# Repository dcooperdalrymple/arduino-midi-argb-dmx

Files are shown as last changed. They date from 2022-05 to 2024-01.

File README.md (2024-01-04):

# Color Spray
> Convert Midi input to ARGB, RGBW, and DMX outputs with an Arduino.

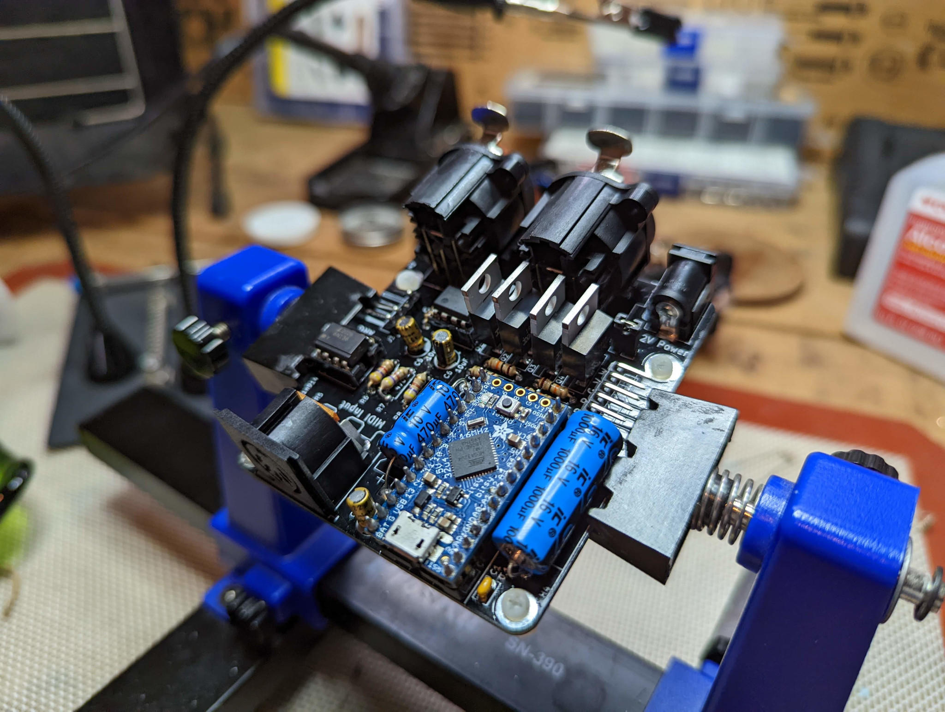
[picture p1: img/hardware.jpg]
Rev1 populated PCB


## Hardware
This project is designed specifically for the [Adafruit Itsy Bitsy 32u4 - 5V 16MHz](https://learn.adafruit.com/introducting-itsy-bitsy-32u4/), but any other Arduino-compatible MCU with similar specifications should be usable with minor modifications. The PCB design will require modification to use a different development board.

For 5V/12V RGBW operation, you can choose between NPN or N-channel MOSFETs in a TO-220 package _(ie: IRF540N, IRLB8721, or TIP-120)_. The resistors before the gate may not be necessary if you use a MOSFET, but are necessary if you use an NPN transistor. If you are using 5V LEDs, you'll need to bridge JP1 and make sure not to also plug a 12V source into the barrel jack at the same time or you may fry the arduino and any devices plugged into the ARGB connectors. If you use 12V LEDs, make sure that JP1 is not connected and provide a separate 12V power source into the barrel jack that is center-positive.

An XLR connector is provided as an alternative to the ARGB pin header. This connector is non-standard and is intended for custom installations where long, secure cable runs are desired. Avoid mixing the DMX and ARGB connections, though I've attempted to make their pinouts very similar to avoid shorting.

## Configuration
The device's configuration is stored within the internal EEPROM memory of the Atmel 32u4. If the appropriate configuration settings aren't already installed, the device will reformat the EEPROM to it's default settings. Midi SysEx messages are used in order to read and write new configuration settings.

A python-based configurator GUI program is provided to help read, backup, and write device configuration to the Color Spray. The program can be run after installing all [dependencies](configurator/manual.md#dependencies) by running `python configurator/configurator.py` from the root directory of the repository. More information is provided in the [manual](configurator/manual.md).

<p float="left">
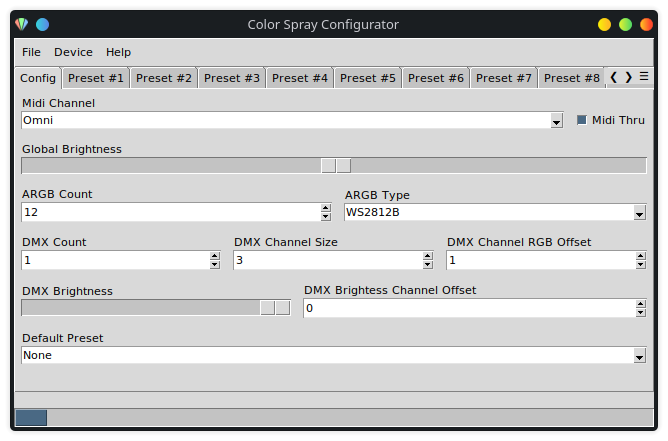
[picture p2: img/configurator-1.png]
Color Spray Configurator Config Panel
    
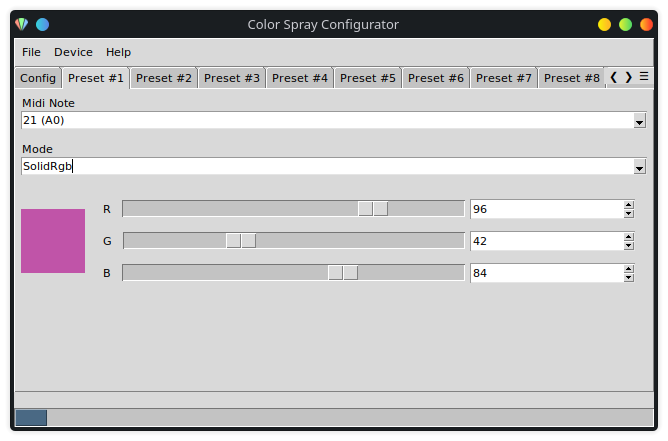
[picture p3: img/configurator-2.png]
Color Spray Configurator Preset Panel
    
</p>

## MIDI Implementation

### Configuration

> Depending on how the software is compiled and uploaded to the Arduino, you can use hardware UART Midi or USB Midi to control this device. The Rev1 PCB is configured with a DIN-5 Midi input only. Future revisions may include Midi output.

Change the `USB_MIDI` definition to enable USB Midi input support. The `MIDI_THRU` definition will enable Midi Thru support via hardware UART and USB if it is enabled.

By default, the `MIDI_CHANNEL` definition is set to Omni mode. This will accept all compatible incoming messages on any channel. Change the value of this definition to a number between 1-16 to assign this device to a particular Midi channel.

### Midi Thru

Some software-based Midi Thru functionality is included, but not all message types are supported. It is recommended that you use a hardware Midi Thru device in conjuction if you intend to use multiple devices on the same output.

### Program Change

> More program modes are planned for the future.

| Program | Description |
| --- | --- |
| 0 | Off |
| 1-15 | Load Preset # |
| 16 | Solid RGB |
| 17 | Solid HSV |
| 18 | Palette Cycle |
| 19 | Chase RGB |
| 20 | Chase HSV |

### Control Change

Control change messages are generally allocated to different General Purpose Controller functions and are separated for each program mode.

| Control | Function | Value (0-127, scaled) | Program |
| --- | --- | --- | --- |
| 12 | Palette | _See Available Palettes_ | Palette Cycle |
| 13 | Speed | 0-4 | Palette Cycle & Chase |
| 16 | Red | 0-254 | Solid RGB & Chase RGB |
| 17 | Green | 0-254 | Solid RGB & Chase RGB |
| 18 | Blue | 0-254 | Solid RGB & Chase RGB |
| 80 | Hue | 0-254 | Solid HSV & Chase HSV |
| 81 | Saturation | 0-254 | Solid HSV & Chase HSV |
| 82 | Value | 0-254 | Solid HSV & Chase HSV |
| 83 | Count | 1-8 | Chase RGB & Chase HSV |

#### Palettes

There are 8 palettes available all contributed by the _FastLED_ library. Custom palettes can be added relatively easily prior to compilation. See the [FastLED wiki](https://github.com/FastLED/FastLED/wiki/Gradient-color-palettes) for more details.

| Index | Midi CC Value | Palette |
| ----- | --- | --- |
| 0 | 0-15 | Cloud |
| 1 | 16-31 | Lava |
| 2 | 32-47 | Ocean |
| 3 | 48-63 | Forest |
| 4 | 64-79 | Rainbow |
| 5 | 80-95 | Rainbow Stripe |
| 6 | 96-111 | Party |
| 7 | 112-127 | Heat |

## DAW Plugins

> The only plugin provided for improved control and synchronization of this device is written for REAPER. The specifications are all provided for extending support to other platforms, but that is not planned currently.

### REAPER (JSFX)

Use the provided sliders to configure this device or enable trim automation on each setting to synchronize your lighting to your song.

Copy and paste `plugins/color-spray-jsfx` into your REAPER JSFX install directory (ie: .../REAPER/Effects). Add the plugin to a track in your project; it will be named _Color Spray_.

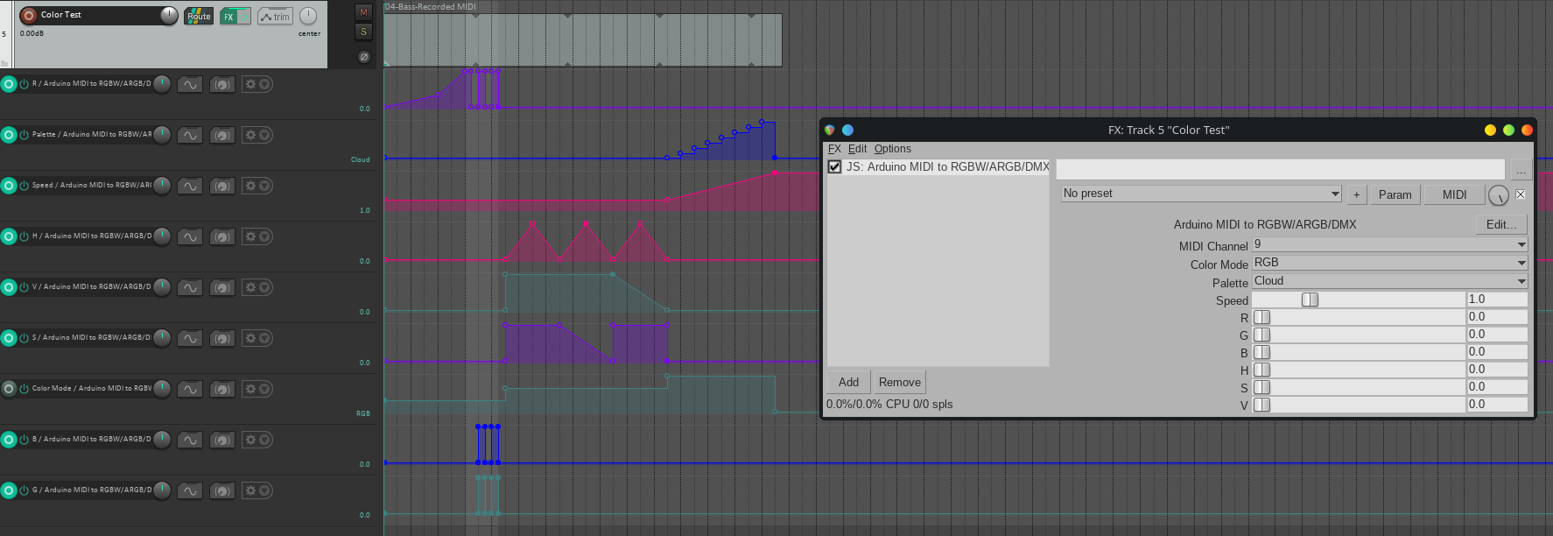
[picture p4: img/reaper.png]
REAPER plugin and example


## Software Dependencies
* [MIDI](https://github.com/FortySevenEffects/arduino_midi_library/)
* [Arduino USB-MIDI Transport](https://github.com/lathoub/Arduino-USBMIDI)
* [FastLED](https://fastled.io/)
* [DmxSimple](https://github.com/PaulStoffregen/DmxSimple)
* [digitalWriteFast](https://github.com/NicksonYap/digitalWriteFast)

---

[OSHW] US002117 | Certified open source hardware | oshwa.org/cert.

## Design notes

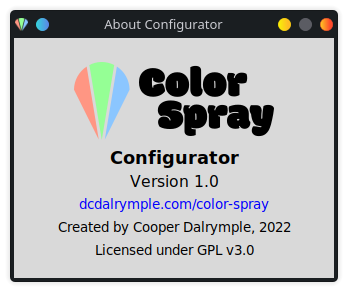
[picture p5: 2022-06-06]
img/configurator-3.png

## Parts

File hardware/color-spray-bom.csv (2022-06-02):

Source: | color-spray.kicad_sch
Date: | Mon 09 May 2022 02:39:10 PM CDT
Tool: | Eeschema 6.0.4+dfsg-1+b1
Generator: | /usr/share/kicad/plugins/bom_csv_grouped_by_value.py
Component Count: | 34
Individual Components:
Item | Qty | Reference(s) | Value | LibPart | Footprint | Datasheet
 |  | C1 | 0.1uF | Device:C | Capacitor_THT:C_Rect_L4.0mm_W2.5mm_P2.50mm | ~
 |  | C2 | 470uF | Device:C_Polarized | Capacitor_THT:CP_Axial_L20.0mm_D10.0mm_P26.00mm_Horizontal | ~
 |  | C3 | 10uF | Device:C_Polarized | Capacitor_THT:CP_Radial_D5.0mm_P2.50mm | ~
 |  | C4 | 1000uF | Device:C_Polarized | Capacitor_THT:CP_Axial_L20.0mm_D10.0mm_P26.00mm_Horizontal | ~
 |  | C5 | 10uF | Device:C_Polarized | Capacitor_THT:CP_Radial_D5.0mm_P2.50mm | ~
 |  | C6 | 10uF | Device:C_Polarized | Capacitor_THT:CP_Radial_D5.0mm_P2.50mm | ~
 |  | D1 | 1N914 | Diode:1N914 | Diode_THT:D_DO-35_SOD27_P7.62mm_Horizontal | http://www.vishay.com/docs/85622/1n914.pdf
 |  | H1 | Mount | Mechanical:MountingHole_Pad | MountingHole:MountingHole_3.2mm_M3_Pad | ~
 |  | H2 | Mount | Mechanical:MountingHole_Pad | MountingHole:MountingHole_3.2mm_M3_Pad | ~
 |  | H3 | Mount | Mechanical:MountingHole_Pad | MountingHole:MountingHole_3.2mm_M3_Pad | ~
 |  | H4 | Mount | Mechanical:MountingHole_Pad | MountingHole:MountingHole_3.2mm_M3_Pad | ~
 |  | J1 | MIDI Input | Connector:DIN-5_180degree | w_conn_av:din-5 | http://www.mouser.com/ds/2/18/40_c091_abd_e-75918.pdf
 |  | J2 | ARGB_XLR3 | Connector:XLR3_Ground | Connector_Audio:Jack_XLR_Neutrik_NC3FAAH2_Horizontal | ~
 |  | J3 | ARGB | Connector:Conn_01x04_Male | Connector_PinHeader_2.54mm:PinHeader_1x04_P2.54mm_Horizontal | ~
 |  | J4 | DMX_XLR3 | Connector:XLR3_Ground | Connector_Audio:Jack_XLR_Neutrik_NC3FAAH2_Horizontal | ~
 |  | J5 | External RGBW Power | Connector:Barrel_Jack | Connector_BarrelJack:BarrelJack_Horizontal | ~
 |  | J6 | RGBW | Connector:Conn_01x05_Male | Connector_PinHeader_2.54mm:PinHeader_1x05_P2.54mm_Horizontal | ~
 |  | JP1 | Jumper_2_Open | Jumper:Jumper_2_Open | Connector_PinHeader_2.54mm:PinHeader_1x02_P2.54mm_Vertical | ~
 |  | Q1 | IRLB8721PBF | Transistor_FET:IRLB8721PBF | Package_TO_SOT_THT:TO-220-3_Vertical | http://www.infineon.com/dgdl/irlb8721pbf.pdf?fileId=5546d462533600a40153566056732591
 |  | Q2 | IRLB8721PBF | Transistor_FET:IRLB8721PBF | Package_TO_SOT_THT:TO-220-3_Vertical | http://www.infineon.com/dgdl/irlb8721pbf.pdf?fileId=5546d462533600a40153566056732591
 |  | Q3 | IRLB8721PBF | Transistor_FET:IRLB8721PBF | Package_TO_SOT_THT:TO-220-3_Vertical | http://www.infineon.com/dgdl/irlb8721pbf.pdf?fileId=5546d462533600a40153566056732591
 |  | Q4 | IRLB8721PBF | Transistor_FET:IRLB8721PBF | Package_TO_SOT_THT:TO-220-3_Vertical | http://www.infineon.com/dgdl/irlb8721pbf.pdf?fileId=5546d462533600a40153566056732591
 |  | R1 | 1k | Device:R | Resistor_THT:R_Axial_DIN0207_L6.3mm_D2.5mm_P7.62mm_Horizontal | ~
 |  | R2 | 1k | Device:R | Resistor_THT:R_Axial_DIN0207_L6.3mm_D2.5mm_P7.62mm_Horizontal | ~
 |  | R3 | 1k | Device:R | Resistor_THT:R_Axial_DIN0207_L6.3mm_D2.5mm_P7.62mm_Horizontal | ~
 |  | R4 | 1k | Device:R | Resistor_THT:R_Axial_DIN0207_L6.3mm_D2.5mm_P7.62mm_Horizontal | ~
 |  | R5 | 220 | Device:R | Resistor_THT:R_Axial_DIN0207_L6.3mm_D2.5mm_P7.62mm_Horizontal | ~
 |  | R6 | 4.7k | Device:R | Resistor_THT:R_Axial_DIN0207_L6.3mm_D2.5mm_P7.62mm_Horizontal | ~
 |  | R7 | 470 | Device:R | Resistor_THT:R_Axial_DIN0207_L6.3mm_D2.5mm_P7.62mm_Horizontal | ~
 |  | R8 | 470 | Device:R | Resistor_THT:R_Axial_DIN0207_L6.3mm_D2.5mm_P7.62mm_Horizontal | ~
 |  | R9 | 100 | Device:R | Resistor_THT:R_Axial_DIN0207_L6.3mm_D2.5mm_P7.62mm_Horizontal | ~
 |  | U1 | ItsyBitsy-32u4-5V | ItsyBitsy 32u4 5V:ItsyBitsy-32u4-5V | itsybitsy-32u4-5v:ItsyBitsy_32u4
 |  | U2 | 6N138 | Isolator:6N138 | Package_DIP:DIP-8_W7.62mm_Socket_LongPads | http://www.onsemi.com/pub/Collateral/HCPL2731-D.pdf
 |  | U3 | SN75176AP | Interface_UART:SN75176AP | Package_DIP:DIP-8_W7.62mm_Socket_LongPads | http://www.ti.com/lit/ds/symlink/sn75176a.pdf
Collated Components:
Item | Qty | Reference(s) | Value | LibPart | Footprint | Datasheet
1 | 1 | C1 | 0.1uF | Device:C | Capacitor_THT:C_Rect_L4.0mm_W2.5mm_P2.50mm | ~
2 | 1 | C2 | 470uF | Device:C_Polarized | Capacitor_THT:CP_Axial_L20.0mm_D10.0mm_P26.00mm_Horizontal | ~
3 | 3 | C3, C5, C6 | 10uF | Device:C_Polarized | Capacitor_THT:CP_Radial_D5.0mm_P2.50mm | ~
4 | 1 | C4 | 1000uF | Device:C_Polarized | Capacitor_THT:CP_Axial_L20.0mm_D10.0mm_P26.00mm_Horizontal | ~
5 | 1 | D1 | 1N914 | Diode:1N914 | Diode_THT:D_DO-35_SOD27_P7.62mm_Horizontal | http://www.vishay.com/docs/85622/1n914.pdf
6 | 4 | H1, H2, H3, H4 | Mount | Mechanical:MountingHole_Pad | MountingHole:MountingHole_3.2mm_M3_Pad | ~
7 | 1 | J1 | MIDI Input | Connector:DIN-5_180degree | w_conn_av:din-5 | http://www.mouser.com/ds/2/18/40_c091_abd_e-75918.pdf
8 | 1 | J2 | ARGB_XLR3 | Connector:XLR3_Ground | Connector_Audio:Jack_XLR_Neutrik_NC3FAAH2_Horizontal | ~
9 | 1 | J3 | ARGB | Connector:Conn_01x04_Male | Connector_PinHeader_2.54mm:PinHeader_1x04_P2.54mm_Horizontal | ~
10 | 1 | J4 | DMX_XLR3 | Connector:XLR3_Ground | Connector_Audio:Jack_XLR_Neutrik_NC3FAAH2_Horizontal | ~
11 | 1 | J5 | External RGBW Power | Connector:Barrel_Jack | Connector_BarrelJack:BarrelJack_Horizontal | ~
12 | 1 | J6 | RGBW | Connector:Conn_01x05_Male | Connector_PinHeader_2.54mm:PinHeader_1x05_P2.54mm_Horizontal | ~
13 | 1 | JP1 | Jumper_2_Open | Jumper:Jumper_2_Open | Connector_PinHeader_2.54mm:PinHeader_1x02_P2.54mm_Vertical | ~
14 | 4 | Q1, Q2, Q3, Q4 | IRLB8721PBF | Transistor_FET:IRLB8721PBF | Package_TO_SOT_THT:TO-220-3_Vertical | http://www.infineon.com/dgdl/irlb8721pbf.pdf?fileId=5546d462533600a40153566056732591
15 | 4 | R1, R2, R3, R4 | 1k | Device:R | Resistor_THT:R_Axial_DIN0207_L6.3mm_D2.5mm_P7.62mm_Horizontal | ~
16 | 1 | R5 | 220 | Device:R | Resistor_THT:R_Axial_DIN0207_L6.3mm_D2.5mm_P7.62mm_Horizontal | ~
17 | 1 | R6 | 4.7k | Device:R | Resistor_THT:R_Axial_DIN0207_L6.3mm_D2.5mm_P7.62mm_Horizontal | ~
18 | 2 | R7, R8 | 470 | Device:R | Resistor_THT:R_Axial_DIN0207_L6.3mm_D2.5mm_P7.62mm_Horizontal | ~
19 | 1 | R9 | 100 | Device:R | Resistor_THT:R_Axial_DIN0207_L6.3mm_D2.5mm_P7.62mm_Horizontal | ~
20 | 1 | U1 | ItsyBitsy-32u4-5V | ItsyBitsy 32u4 5V:ItsyBitsy-32u4-5V | itsybitsy-32u4-5v:ItsyBitsy_32u4
21 | 1 | U2 | 6N138 | Isolator:6N138 | Package_DIP:DIP-8_W7.62mm_Socket_LongPads | http://www.onsemi.com/pub/Collateral/HCPL2731-D.pdf
22 | 1 | U3 | SN75176AP | Interface_UART:SN75176AP | Package_DIP:DIP-8_W7.62mm_Socket_LongPads | http://www.ti.com/lit/ds/symlink/sn75176a.pdf

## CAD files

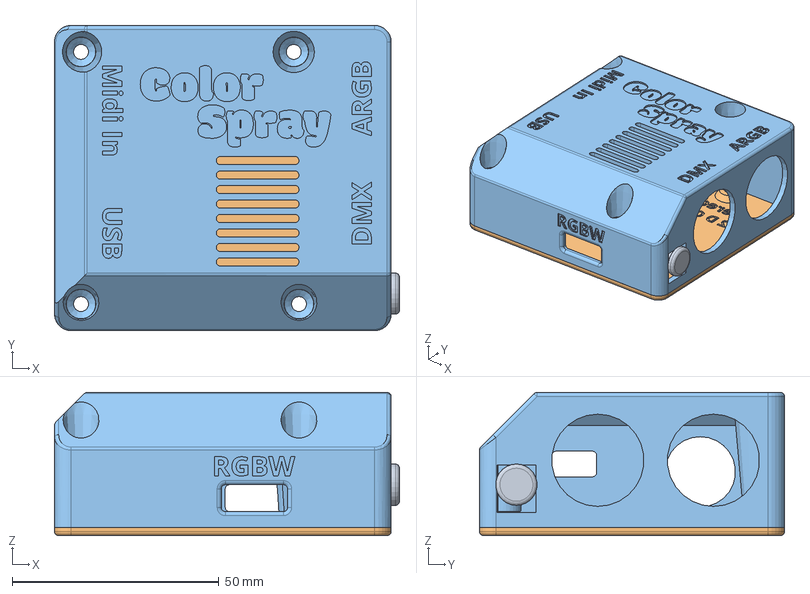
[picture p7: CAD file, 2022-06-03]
enclosure/color-spray.FCStd
83.4 x 73.8 x 34.6 mm
DC Cap
Lower Body with Labels
Upper Body with Labels

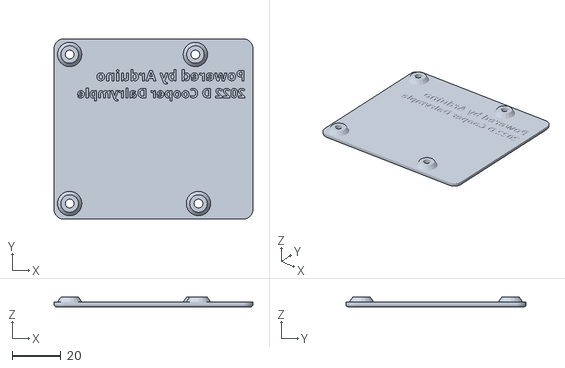
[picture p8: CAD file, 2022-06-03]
enclosure/bottom.stl
81.4 x 73.8 x 4.00

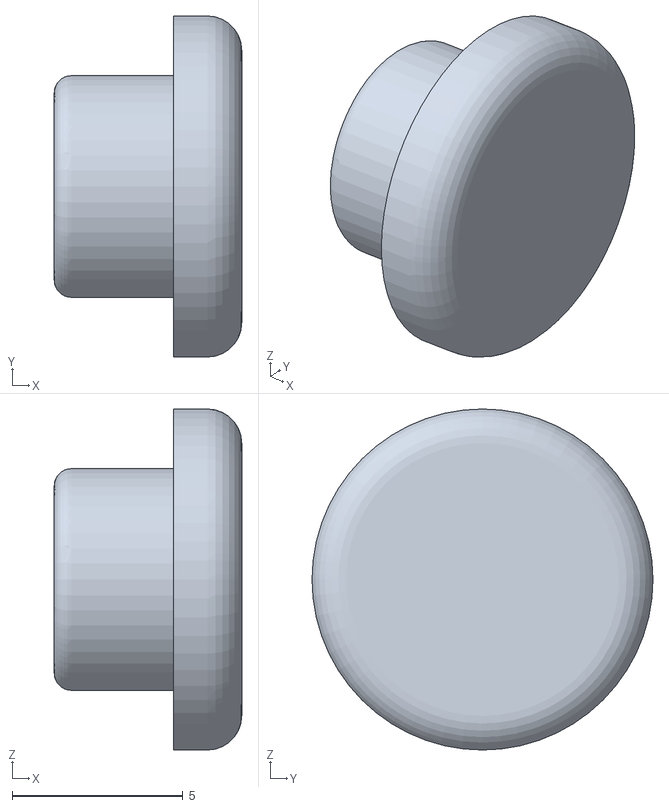
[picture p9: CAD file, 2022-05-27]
enclosure/dc-cap.stl
5.50 x 10.0 x 10.0

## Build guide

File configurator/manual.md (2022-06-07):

# Color Spray Configurator
> Configure the settings and presets of the Color Spray midi light controller.

## Table of Contents
1. [Config](#config)
   * [Midi Channel](#midi-channel)
   * [Midi Thru](#midi-thru)
   * [Global Brightness](#global-brightness)
   * [ARGB Count](#argb-count)
   * [ARGB Type](#argb-type)
   * [DMX](#dmx)
     * [Count](#dmx-count)
     * [Channel Size](#dmx-channel-size)
     * [RGB Offset](#dmx-rgb-offset)
     * [Brightness](#dmx-brightness)
     * [Brightness Channel](#dmx-brightness-channel)
2. [Presets](#preset)
   * [Program Number](#preset-program)
   * [Note](#preset-note)
   * [Mode](#preset-mode)
3. [Saving & Loading JSON Files](#json)
   * [Saving a JSON File](#json-save)
   * [Loading a JSON File](#json-load)
   * [Modifying JSON Files](#json-modify)
4. [Reading & Writing to Device](#device)
   * [Selecting the Device's Port](#device-port)
   * [Reading from the Device](#device-read)
   * [Writing from the Device](#device-write)
   * [Software Reset](#device-reset)
5. [Software Dependencies](#dependencies)

---

## Config<span id="config" />
The settings in this area will apply to all device operations. Most settings will take effect with a software reset after the device is written to, but some (such as the _ARGB Type_) may require a hardware reset before they take affect.

### Midi Channel<span id="midi-channel" />
Choose the desired midi channel to accept all midi messages: control change, program change, and note on. By default, the device is configured for _Omni_ mode where it will accept all messages. Changing the midi channel won't have any affect on reading and writing device configuration settings.

### Midi Thru<span id="midi-thru" />
If you'd like to transfer messages from the midi input to the output buffer, check the Midi Thru box. Messages will be transferred no matter what channel they are set to. The messages will be transferred according to the following table:

| Input Port | Output Ports |
| --- | --- |
| UART In | UART Out, USB Out |
| USB In | UART Out |

> To prevent unnecessary loopback, USB is not set in Thru mode.
> By leaving Midi Thru enabled, it may slow down the device's responsiveness. If not needed, it is recommended that you leave Midi Thru disabled.

### Global Brightness<span id="global-brightness" />
By default, this setting is set to 50% where the color settings are unaffected. Drag the brightness slider down to lower the overall color intensity or higher to increase and potentially wash out your colors.

### ARGB Count<span id="argb-count" />
To individually control each LED in an ARGB strip, you will need to predefine the number of LEDs with this setting. You are allowed a maximum of 128 addressable LEDs and a minimum of 1.

### ARGB Type<span id="argb-type" />
WD2812B is set as the default ARGB controller, but depending on the type of LEDs you are controlling, you may need to change this setting. You can find more information on each chipset type [here](https://github.com/FastLED/FastLED/wiki/Overview#supported-chipsets). More chipset than the provided are supported but will require firmware re-compilation to enable.

### DMX<span id="dmx" />
You can control DMX lights simultaneously all on the same channels, but if you'd like to address each DMX light independently, you can use the following settings.

> It is not currently possible to configure lights independently. It is recommended that you use the same types of RGB lights together to avoid channel overlaps. Independent DMX device configuration may come in a future release.

DMX communication is limited to 512 channels. Make sure that your settings don't exceed 512 channels in total. The calculation to determine the total number of channels is as follows: `Count * Channel Size`.

#### Count<span id="dmx-count" />
Specify the number of devices that you'd like to control. You must at least have 1 device accounted for.

#### Channel Size<span id="dmx-channel-size" />
Specify the number of channels each device will be allocated. You may have to look up the specifications for the device's DMX utilization. A minimum of 3 channels can be allotted to account for the RGB channels and a maximum of 32 channels per device is allowed.

#### RGB Offset<span id="dmx-rgb-offset" />
Your device may have its RGB channels start after the first channel. Pick a value between 1 and 2 less that the total channel size to correct control your specific lights.

> By default, the order of color channels is *RGB*. If you need to change this, the firmware will need to be recompiled with a different setting for the `DMX_ORDER` definition.

#### Brightness<span id="dmx-brightness" />
Your DMX lights may have a specific channel used to control the overal brightness of the lights. You can specify the static brightness amount using this slider. By default, the brightness is set at its max of 127.

#### Brightness Channel<span id="dmx-brightness-channel" />
If your device has a dedicated brightness channel, you can specify it here as an offset of each device's first channel. If you leave this setting as 0, the brightness channel will be ignored.

---

## Presets<span id="preset" />
The Color Spray has 15 presets available. Each preset contains the same settings which can be configured live with midi control commands. These presets can be loaded when the device boots up, when a midi program change message is received, or when a midi note on message is received if the device is configured to do so.

### Program Number<span id="preset-program" />
If a midi program change message is received, the Color Spray will load up the appropriate preset from 1-15. If the program # is 0, the device will be set to the `ColorOff` mode. Program #'s from 16+ are reserved for changing color modes dynamically.

The assigned index of the preset will be given by the name of the selected preset tab.

### Note<span id="preset-note" />
By assigning a note value to a preset, the preset can be loaded by sending a midi note on message to the device that matches the assigned pitch. If multiple presets are assigned to the same pitch, the preset whose program number comes first will be loaded.

### Mode<span id="preset-mode" />
By default, each preset is set to the color mode `ColorOff`. This essentially deactivates the preset and prevents any light from emitting from connected devices. The available modes and their functionality are listed below:

#### SolidRGB<span id="preset-mode-solidrgb" />
Set a solid RGB color for all lights to be set. The Red, Green, and Blue settings can be set between 0 and 127 and be controlled using the slider from left to right or by manually typing in your desired value in the number box. Use the preview window to help you find the desired color.

#### SolidHSV<span id="preset-mode-solidhsv" />
Set a solid HSV color for all lights to be set. The Hue, Saturation, and Value settings can be set between 0 and 127 and be controlled using the slider from left to right or by manually typing in your desired value in the number box. Use the preview window to help you find the desired color.

#### Palette<span id="preset-mode-palette" />
Loop through a pre-defined set of colors at a variable speed. There are 8 palette options available: Cloud, Lava, Ocean, Forest, Rainbow, Rainbow Stripe, Party, and Heat. A speed value is provided to define how fast the lights will rotate through the palette.

#### ChaseRGB<span id="preset-mode-chasergb" />
Rotate a solid RGB color around all available addressable lights in a "Chase" manner. You can control the desired _color_ using the SolidRGB settings, the _speed_ of the rotation, and the number of chase lights, _count_ (essentially the gap between the selected color).

#### ChaseHSV<span id="preset-mode-chasehsv" />
Rotate a solid HSV color around all available addressable lights in a "Chase" manner. You can control the desired _color_ using the SolidHSV settings, the _speed_ of the rotation, and the number of chase lights, _count_ (essentially the gap between the selected color).

---

## Saving & Loading JSON Files<span id="json" />
Before writing to the device, it is recommended that you save a backup copy of your settings to a safe location in your drive.

### Saving a JSON File<span id="json-save" />
Under the *File* menu in the top left, there is a *Save* and *Load* option. By clicking the *Save* option, it will open up a file prompt for you to select your desired file name and location. After clicking the OK button, a copy of all Config and Presets settings will be saved in the JSON format.

### Loading a JSON File<span id="json-load" />
If you have a previously saved configurator backup file available, you can load it using the *Load* option under the *File* menu in the top left corner of the window. A file prompt should appear where you can select the `*.json` file which you saved earlier. If an incompatible file is loaded, the program will prompt you that an error occurred and you will need to try again. Backup files saved with previous versions of the configurator software may not be compatible with the current software. When the file has finished loading, all of the controls within the configurator should be updated to show the new settings. If a device is connected, it will not be automatically synchronized in this process.

### Modifying JSON Files<span id="json-modify" />
If it fits your workflow style, you can modify the Color Spray JSON files outside of the configurator using any plain text editor. As long as the Manufacturer ID, Device ID, and Version settings remain unchanged, the configurator should attempt to load the altered file. It may be possible to affect the program in unforeseen ways, so only attempt this if you are willing to lose your original data and potentially harm the device's firmware.

---

## Reading & Writing to Device<span id="device" />
Communication with the _Color Spray_ occurs over a standard MIDI connection using the Sysex protocol. The device will need to be connected in duplex through either a hardware MIDI interface or with the built-in USB-MIDI interface of the device. A USB connection is highly recommended during this process for it's ease of use and reliability.

### Selecting the Device's Port<span id="device-port" />
A list of all MIDI devices available to your computer will be listed within the *Device* menu under *Ports*. If you haven't yet connected your device, you can do so then select the top item under *Ports* labeled *Refresh*. This will disconnect any midi connection you may have activated and refresh the list of available MIDI ports.

The USB-MIDI interface of the device should be labeled as `Color Spray 32u4`. Select this port in the menu to initialize the connection. If there is any issue, you should be prompted of the error.

### Reading from the Device<span id="device-read" />
Reading all device settings from the _Color Spray_ is very simple. Once you've connected to its MIDI port, you'll need to selected *Read* under the *Device* menu. This will check the status and firmware of the device to ensure compatibility then begin to load the global configuration settings and all 15 presets from the device's memory.

If the read completed successfully, all settings within the configurator program will be updated to reflect the settings of the device. If you'd like to make a backup of the devices settings for future use, now would be a great time.

If any errors occurred during the process, you should be notified of the exact error which occurred. You may need to attempt the process again or manually reset and reconnect to the device if you continue to have problems.

### Writing from the Device<span id="device-write" />
Once you are confident with all of your settings and presets and have made any necessary backups, you can write these settings to the device's memory by selecting *Write* under the *Device* menu.

This process will work very similarly to the read process but send the data in the opposite direction. If a device isn't found, your device's firmware is incompatible, or there are any other unforeseen errors in the process, the operation will cancel and you will be prompted of the error.

After the global configuration and all 15 presets have been written to the device's memory, a reset command will be automatically sent to the device for it to use the new settings and reinitialize any connected addressable lighting devices.

### Software Reset<span id="device-reset" />
For any reason if you'd like to manually reset the device's software, you can do so using the *Reset* option under the *Device* menu. This will not perform a hardware reset to the device but instead reload any stored settings and reinitialize the device's configuration.

If you'd like to perform a hardware reset which may be necessary to resolve some issues, you can do so either by powering off and powering on the device or by pressing the internal reset button which may require disassembly.

---

## Software Dependencies<span id="dependencies" />
In order to run the configurator too, you will need Python 3.0+ and a few pip packages. After you've resolved all dependencies, run the program using `python configurator.py`.

### Linux (Ubuntu/Debian)<span id="dependencies-linux" />
```
sudo apt-get update
sudo apt-get install python3 python3-pip python3-is-python
pip install tkinter python-rtmidi tkinterweb
```

### Windows<span id="dependencies-windows" />
Download and install the latest version of Python 3.0+ [here](https://www.python.org/downloads/windows/). PIP should be installed by default since Python 3.4. Within the command line, run the following command to install all dependencies: `python -m pip install tkinter python-rtmidi tkinterweb markdown`.

### Packages<span id="dependencies-packages" />
* [pyython-rtmidi](https://github.com/SpotlightKid/python-rtmidi)
* [tkinterweb](https://github.com/Andereoo/TkinterWeb/)
* [ttkScrollableNotebook](https://github.com/muhammeteminturgut/ttkScrollableNotebook) _(included within repository)_

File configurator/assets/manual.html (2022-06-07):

# Color Spray Configurator

Configure the settings and presets of the Color Spray midi light controller.

## Table of Contents

1. Config
  - Midi Channel
  - Midi Thru
  - Global Brightness
  - ARGB Count
  - ARGB Type
  - DMX
    - Count
    - Channel Size
    - RGB Offset
    - Brightness
    - Brightness Channel
2. Presets
  - Program Number
  - Note
  - Mode
3. Saving & Loading JSON Files
  - Saving a JSON File
  - Loading a JSON File
  - Modifying JSON Files
4. Reading & Writing to Device
  - Selecting the Device's Port
  - Reading from the Device
  - Writing from the Device
  - Software Reset
5. Software Dependencies

## Config

The settings in this area will apply to all device operations. Most settings will take effect with a software reset after the device is written to, but some (such as the ARGB Type) may require a hardware reset before they take affect.

### Midi Channel

Choose the desired midi channel to accept all midi messages: control change, program change, and note on. By default, the device is configured for Omni mode where it will accept all messages. Changing the midi channel won't have any affect on reading and writing device configuration settings.

### Midi Thru

If you'd like to transfer messages from the midi input to the output buffer, check the Midi Thru box. Messages will be transferred no matter what channel they are set to. The messages will be transferred according to the following table:

Input Port | Output Ports
UART In | UART Out, USB Out
USB In | UART Out

To prevent unnecessary loopback, USB is not set in Thru mode. By leaving Midi Thru enabled, it may slow down the device's responsiveness. If not needed, it is recommended that you leave Midi Thru disabled.

### Global Brightness

By default, this setting is set to 50% where the color settings are unaffected. Drag the brightness slider down to lower the overall color intensity or higher to increase and potentially wash out your colors.

### ARGB Count

To individually control each LED in an ARGB strip, you will need to predefine the number of LEDs with this setting. You are allowed a maximum of 128 addressable LEDs and a minimum of 1.

### ARGB Type

WD2812B is set as the default ARGB controller, but depending on the type of LEDs you are controlling, you may need to change this setting. You can find more information on each chipset type here (https://github.com/FastLED/FastLED/wiki/Overview#supported-chipsets). More chipset than the provided are supported but will require firmware re-compilation to enable.

### DMX

You can control DMX lights simultaneously all on the same channels, but if you'd like to address each DMX light independently, you can use the following settings.

It is not currently possible to configure lights independently. It is recommended that you use the same types of RGB lights together to avoid channel overlaps. Independent DMX device configuration may come in a future release.

DMX communication is limited to 512 channels. Make sure that your settings don't exceed 512 channels in total. The calculation to determine the total number of channels is as follows: Count * Channel Size.

#### Count

Specify the number of devices that you'd like to control. You must at least have 1 device accounted for.

#### Channel Size

Specify the number of channels each device will be allocated. You may have to look up the specifications for the device's DMX utilization. A minimum of 3 channels can be allotted to account for the RGB channels and a maximum of 32 channels per device is allowed.

#### RGB Offset

Your device may have its RGB channels start after the first channel. Pick a value between 1 and 2 less that the total channel size to correct control your specific lights.

By default, the order of color channels is RGB. If you need to change this, the firmware will need to be recompiled with a different setting for the DMX_ORDER definition.

#### Brightness

Your DMX lights may have a specific channel used to control the overal brightness of the lights. You can specify the static brightness amount using this slider. By default, the brightness is set at its max of 127.

#### Brightness Channel

If your device has a dedicated brightness channel, you can specify it here as an offset of each device's first channel. If you leave this setting as 0, the brightness channel will be ignored.

## Presets

The Color Spray has 15 presets available. Each preset contains the same settings which can be configured live with midi control commands. These presets can be loaded when the device boots up, when a midi program change message is received, or when a midi note on message is received if the device is configured to do so.

### Program Number

If a midi program change message is received, the Color Spray will load up the appropriate preset from 1-15. If the program # is 0, the device will be set to the ColorOff mode. Program #'s from 16+ are reserved for changing color modes dynamically.

The assigned index of the preset will be given by the name of the selected preset tab.

### Note

By assigning a note value to a preset, the preset can be loaded by sending a midi note on message to the device that matches the assigned pitch. If multiple presets are assigned to the same pitch, the preset whose program number comes first will be loaded.

### Mode

By default, each preset is set to the color mode ColorOff. This essentially deactivates the preset and prevents any light from emitting from connected devices. The available modes and their functionality are listed below:

#### SolidRGB

Set a solid RGB color for all lights to be set. The Red, Green, and Blue settings can be set between 0 and 127 and be controlled using the slider from left to right or by manually typing in your desired value in the number box. Use the preview window to help you find the desired color.

#### SolidHSV

Set a solid HSV color for all lights to be set. The Hue, Saturation, and Value settings can be set between 0 and 127 and be controlled using the slider from left to right or by manually typing in your desired value in the number box. Use the preview window to help you find the desired color.

#### Palette

Loop through a pre-defined set of colors at a variable speed. There are 8 palette options available: Cloud, Lava, Ocean, Forest, Rainbow, Rainbow Stripe, Party, and Heat. A speed value is provided to define how fast the lights will rotate through the palette.

#### ChaseRGB

Rotate a solid RGB color around all available addressable lights in a "Chase" manner. You can control the desired color using the SolidRGB settings, the speed of the rotation, and the number of chase lights, count (essentially the gap between the selected color).

#### ChaseHSV

Rotate a solid HSV color around all available addressable lights in a "Chase" manner. You can control the desired color using the SolidHSV settings, the speed of the rotation, and the number of chase lights, count (essentially the gap between the selected color).

## Saving & Loading JSON Files

Before writing to the device, it is recommended that you save a backup copy of your settings to a safe location in your drive.

### Saving a JSON File

Under the File menu in the top left, there is a Save and Load option. By clicking the Save option, it will open up a file prompt for you to select your desired file name and location. After clicking the OK button, a copy of all Config and Presets settings will be saved in the JSON format.

### Loading a JSON File

If you have a previously saved configurator backup file available, you can load it using the Load option under the File menu in the top left corner of the window. A file prompt should appear where you can select the *.json file which you saved earlier. If an incompatible file is loaded, the program will prompt you that an error occurred and you will need to try again. Backup files saved with previous versions of the configurator software may not be compatible with the current software. When the file has finished loading, all of the controls within the configurator should be updated to show the new settings. If a device is connected, it will not be automatically synchronized in this process.

### Modifying JSON Files

If it fits your workflow style, you can modify the Color Spray JSON files outside of the configurator using any plain text editor. As long as the Manufacturer ID, Device ID, and Version settings remain unchanged, the configurator should attempt to load the altered file. It may be possible to affect the program in unforeseen ways, so only attempt this if you are willing to lose your original data and potentially harm the device's firmware.

## Reading & Writing to Device

Communication with the Color Spray occurs over a standard MIDI connection using the Sysex protocol. The device will need to be connected in duplex through either a hardware MIDI interface or with the built-in USB-MIDI interface of the device. A USB connection is highly recommended during this process for it's ease of use and reliability.

### Selecting the Device's Port

A list of all MIDI devices available to your computer will be listed within the Device menu under Ports. If you haven't yet connected your device, you can do so then select the top item under Ports labeled Refresh. This will disconnect any midi connection you may have activated and refresh the list of available MIDI ports.

The USB-MIDI interface of the device should be labeled as Color Spray 32u4. Select this port in the menu to initialize the connection. If there is any issue, you should be prompted of the error.

### Reading from the Device

Reading all device settings from the Color Spray is very simple. Once you've connected to its MIDI port, you'll need to selected Read under the Device menu. This will check the status and firmware of the device to ensure compatibility then begin to load the global configuration settings and all 15 presets from the device's memory.

If the read completed successfully, all settings within the configurator program will be updated to reflect the settings of the device. If you'd like to make a backup of the devices settings for future use, now would be a great time.

If any errors occurred during the process, you should be notified of the exact error which occurred. You may need to attempt the process again or manually reset and reconnect to the device if you continue to have problems.

### Writing from the Device

Once you are confident with all of your settings and presets and have made any necessary backups, you can write these settings to the device's memory by selecting Write under the Device menu.

This process will work very similarly to the read process but send the data in the opposite direction. If a device isn't found, your device's firmware is incompatible, or there are any other unforeseen errors in the process, the operation will cancel and you will be prompted of the error.

After the global configuration and all 15 presets have been written to the device's memory, a reset command will be automatically sent to the device for it to use the new settings and reinitialize any connected addressable lighting devices.

### Software Reset

For any reason if you'd like to manually reset the device's software, you can do so using the Reset option under the Device menu. This will not perform a hardware reset to the device but instead reload any stored settings and reinitialize the device's configuration.

If you'd like to perform a hardware reset which may be necessary to resolve some issues, you can do so either by powering off and powering on the device or by pressing the internal reset button which may require disassembly.

## Software Dependencies

In order to run the configurator too, you will need Python 3.0+ and a few pip packages. After you've resolved all dependencies, run the program using python configurator.py.

### Linux (Ubuntu/Debian)

sudo apt-get update
sudo apt-get install python3 python3-pip python3-is-python
pip install tkinter python-rtmidi tkinterweb

### Windows

Download and install the latest version of Python 3.0+ here (https://www.python.org/downloads/windows/). PIP should be installed by default since Python 3.4. Within the command line, run the following command to install all dependencies: python -m pip install tkinter python-rtmidi tkinterweb.

### Packages

- pyython-rtmidi (https://github.com/SpotlightKid/python-rtmidi)
- tkinterweb (https://github.com/Andereoo/TkinterWeb/)
- ttkScrollableNotebook (https://github.com/muhammeteminturgut/ttkScrollableNotebook) (included within repository)

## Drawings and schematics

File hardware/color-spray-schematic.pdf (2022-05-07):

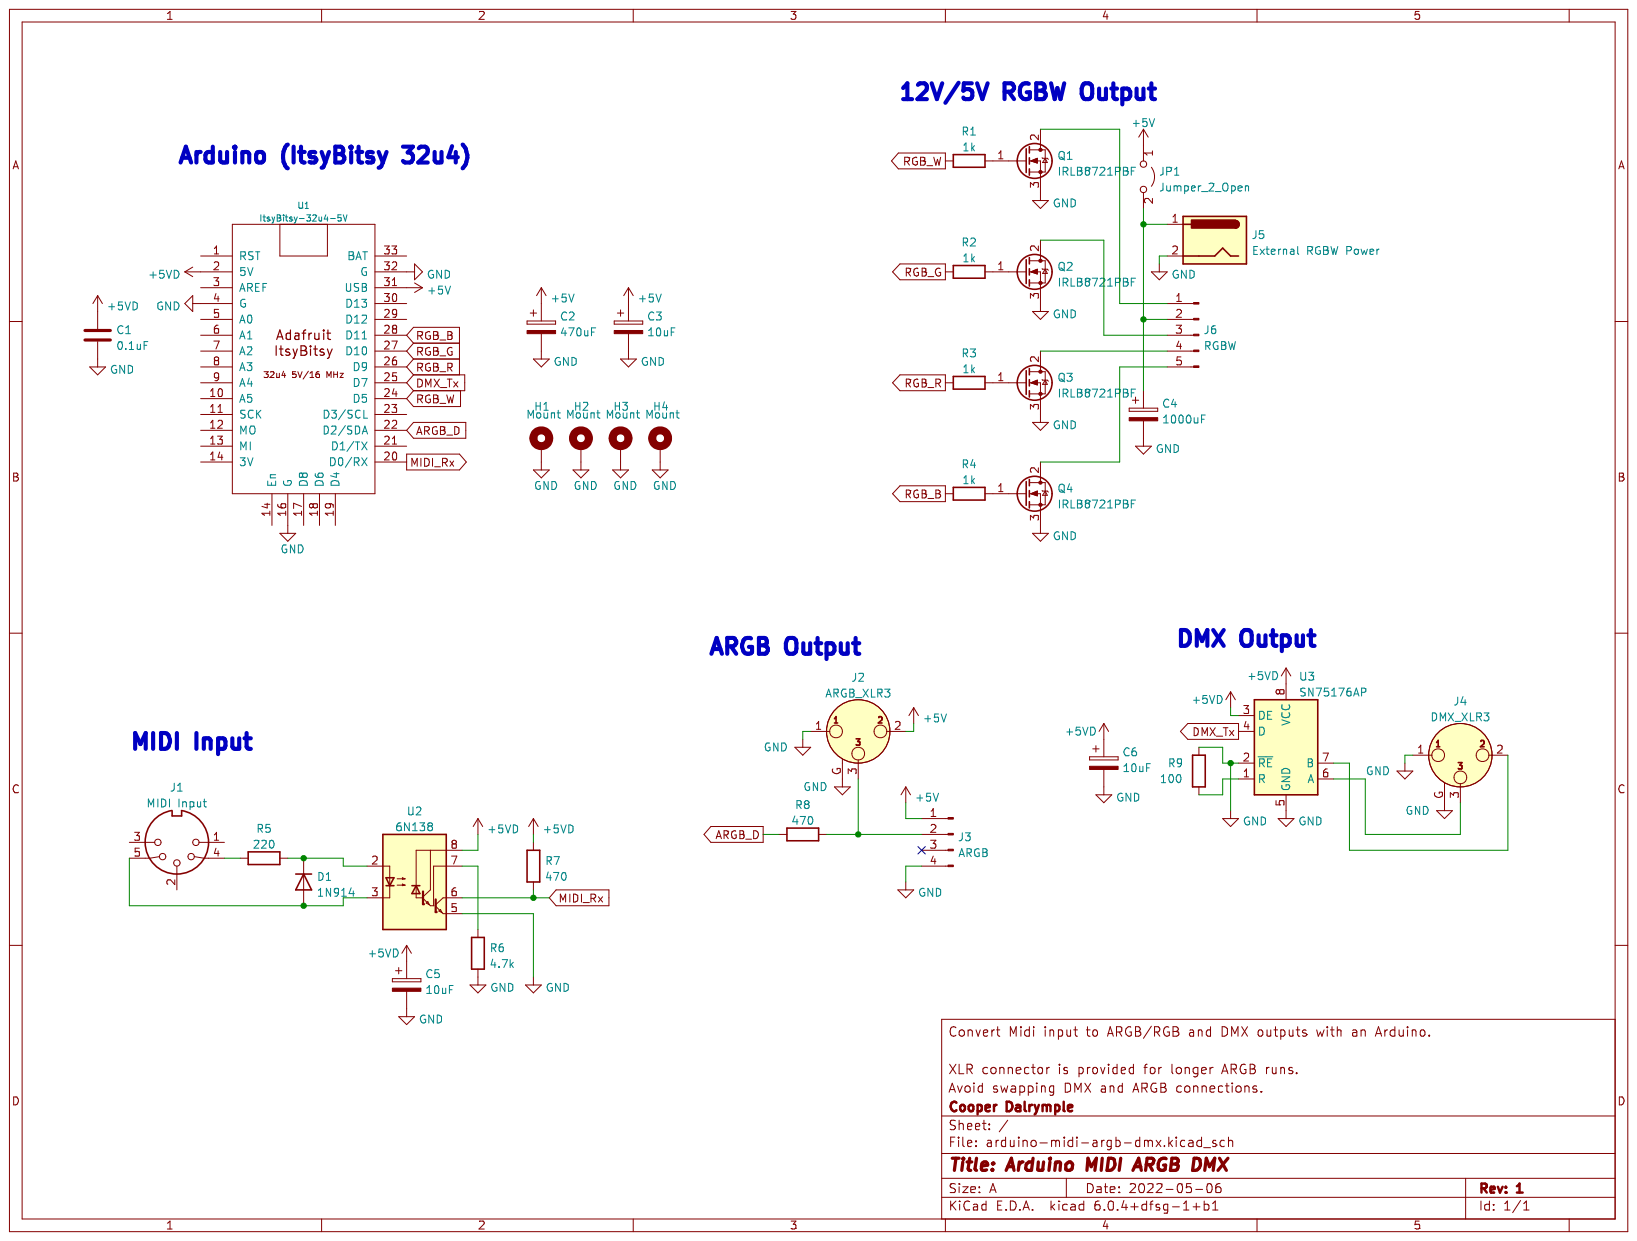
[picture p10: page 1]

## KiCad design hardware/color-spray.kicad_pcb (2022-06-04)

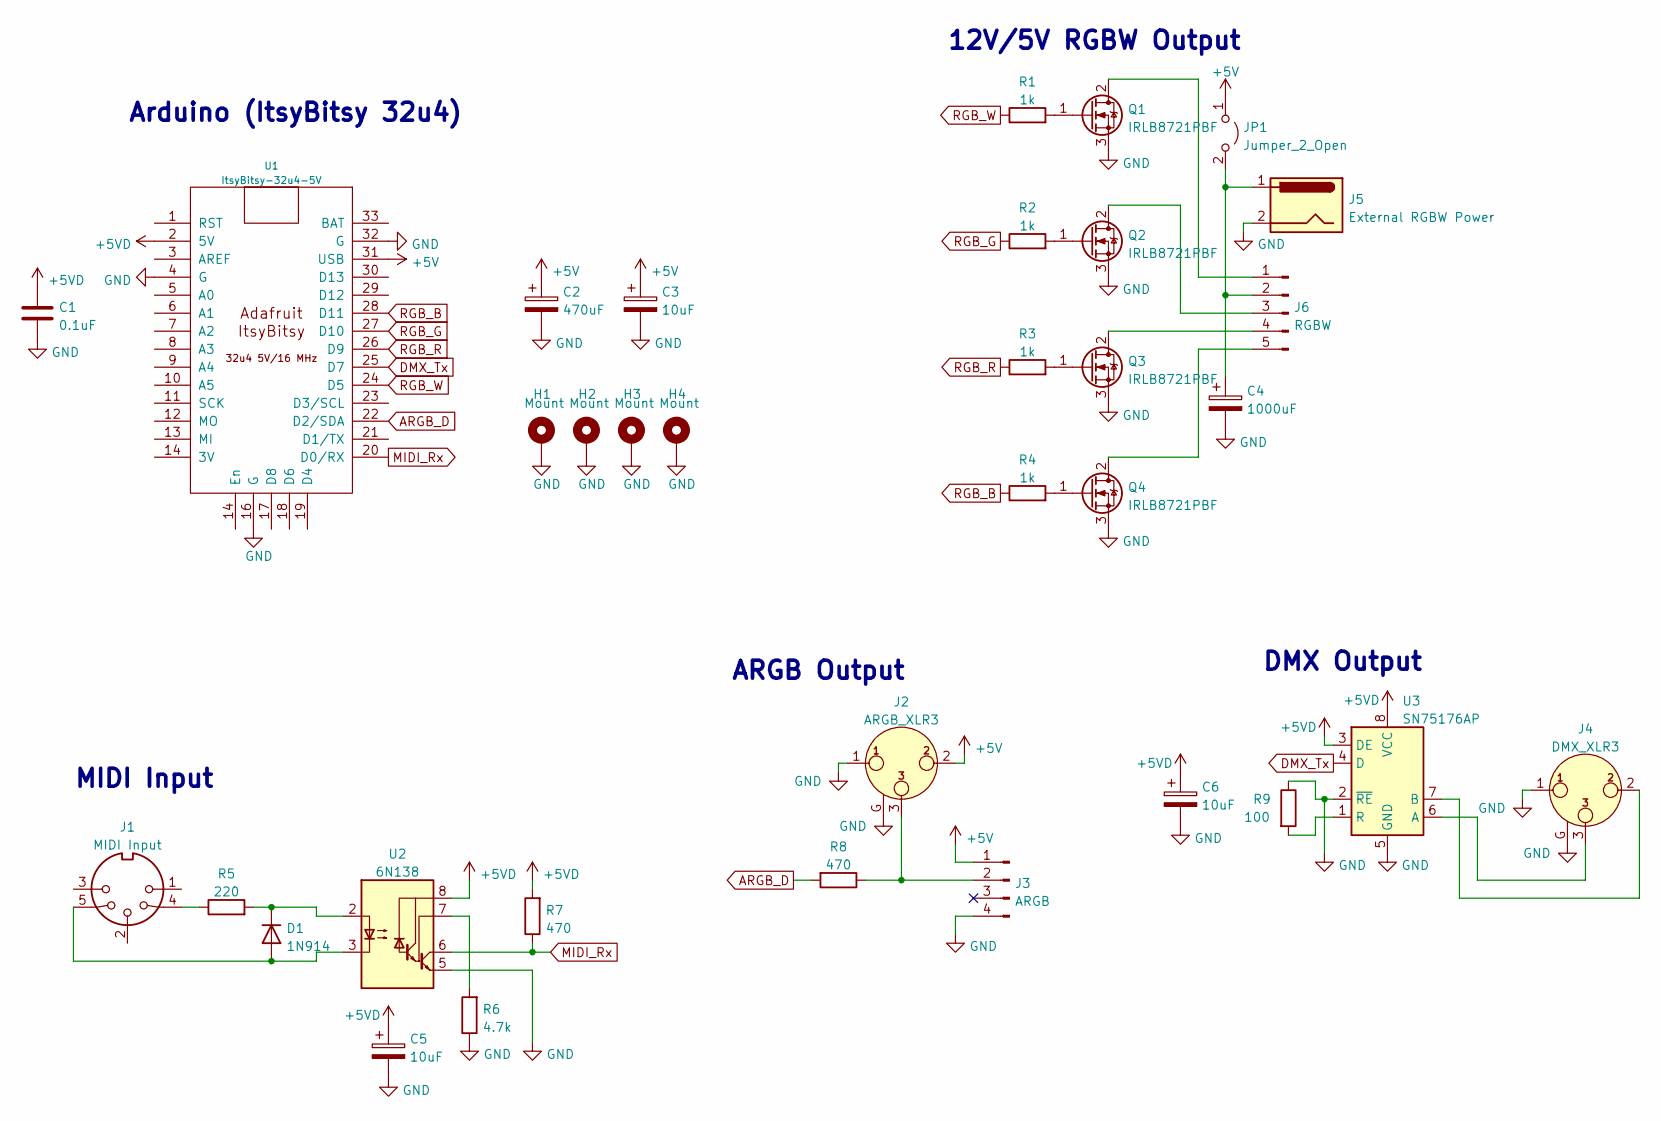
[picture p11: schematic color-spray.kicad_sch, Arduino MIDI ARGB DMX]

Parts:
C1: 0.1uF; C_Rect_L4.0mm_W2.5mm_P2.50mm
C2: 470uF; CP_Axial_L20.0mm_D10.0mm_P26.00mm_Horizontal
C3, C5, C6: 10uF; CP_Radial_D5.0mm_P2.50mm
C4: 1000uF; CP_Axial_L20.0mm_D10.0mm_P26.00mm_Horizontal
D1: 1N914; D_DO-35_SOD27_P7.62mm_Horizontal
H1, H2, H3, H4: Mount; MountingHole_3.2mm_M3_Pad
J1: MIDI Input; din-5
J2: ARGB_XLR3; Jack_XLR_Neutrik_NC3FAAH2_Horizontal
J3: ARGB; PinHeader_1x04_P2.54mm_Horizontal
J4: DMX_XLR3; Jack_XLR_Neutrik_NC3FAAH2_Horizontal
J5: External RGBW Power; BarrelJack_Horizontal
J6: RGBW; PinHeader_1x05_P2.54mm_Horizontal
JP1: Jumper_2_Open; PinHeader_1x02_P2.54mm_Vertical
Q1, Q2, Q3, Q4: IRLB8721PBF; TO-220-3_Vertical
R1, R2, R3, R4: 1k; R_Axial_DIN0207_L6.3mm_D2.5mm_P7.62mm_Horizontal
R5: 220; R_Axial_DIN0207_L6.3mm_D2.5mm_P7.62mm_Horizontal
R6: 4.7k; R_Axial_DIN0207_L6.3mm_D2.5mm_P7.62mm_Horizontal
R7, R8: 470; R_Axial_DIN0207_L6.3mm_D2.5mm_P7.62mm_Horizontal
R9: 100; R_Axial_DIN0207_L6.3mm_D2.5mm_P7.62mm_Horizontal
U1: ItsyBitsy-32u4-5V; ItsyBitsy_32u4
U2: 6N138; DIP-8_W7.62mm_Socket_LongPads
U3: SN75176AP; DIP-8_W7.62mm_Socket_LongPads

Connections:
+5V: C2.1, C3.1, J2.2, J3.1, JP1.1 (A), U1.31 (USB)
+5VD: C1.1, C5.1, C6.1, R7.2, U1.2 (5V), U2.8 (VCC), U3.3 (DE), U3.8 (VCC)
ARGB_D: R8.2, U1.22 (D2/SDA)
DMX_Tx: U1.25 (D7), U3.4 (D)
GND: C1.2, C2.2, C3.2, C4.2, C5.2, C6.2, H1.1, H2.1, H3.1, H4.1, J2.1, J2.G, J3.4, J4.1, J4.G, J5.2, Q1.3 (S), Q2.3 (S), Q3.3 (S), Q4.3 (S), R6.1, R9.1, U1.4 (G), U1.16 (G), U1.32 (G), U2.5 (GND), U3.2 (~RE), U3.5 (GND)
MIDI_Rx: R7.1, U1.20 (D0/RX), U2.6 (VO2)
unnamed: C4.1, J5.1, J6.2, JP1.2 (B)
unnamed: J1.4, R5.1
unnamed: D1.2 (A), J1.5, U2.3 (C2)
unnamed: J2.3, J3.2, R8.1
unnamed: J4.2, U3.7 (B)
unnamed: J4.3, U3.6 (A)
unnamed: J6.3, Q2.2 (D)
unnamed: J6.4, Q3.2 (D)
unnamed: J6.5, Q4.2 (D)
unnamed: J6.1, Q1.2 (D)
unnamed: Q1.1 (G), R1.2
unnamed: Q2.1 (G), R2.2
unnamed: Q3.1 (G), R3.2
unnamed: Q4.1 (G), R4.2
unnamed: D1.1 (K), R5.2, U2.2 (C1)
unnamed: R6.2, U2.7 (VO1)
unnamed: R9.2, U3.1 (R)
RGB_B: R4.1, U1.28 (D11)
RGB_G: R2.1, U1.27 (D10)
RGB_R: R3.1, U1.26 (D9)
RGB_W: R1.1, U1.24 (D5)

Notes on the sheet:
MIDI Input
Arduino (ItsyBitsy 32u4)
ARGB Output
12V/5V RGBW Output
DMX Output

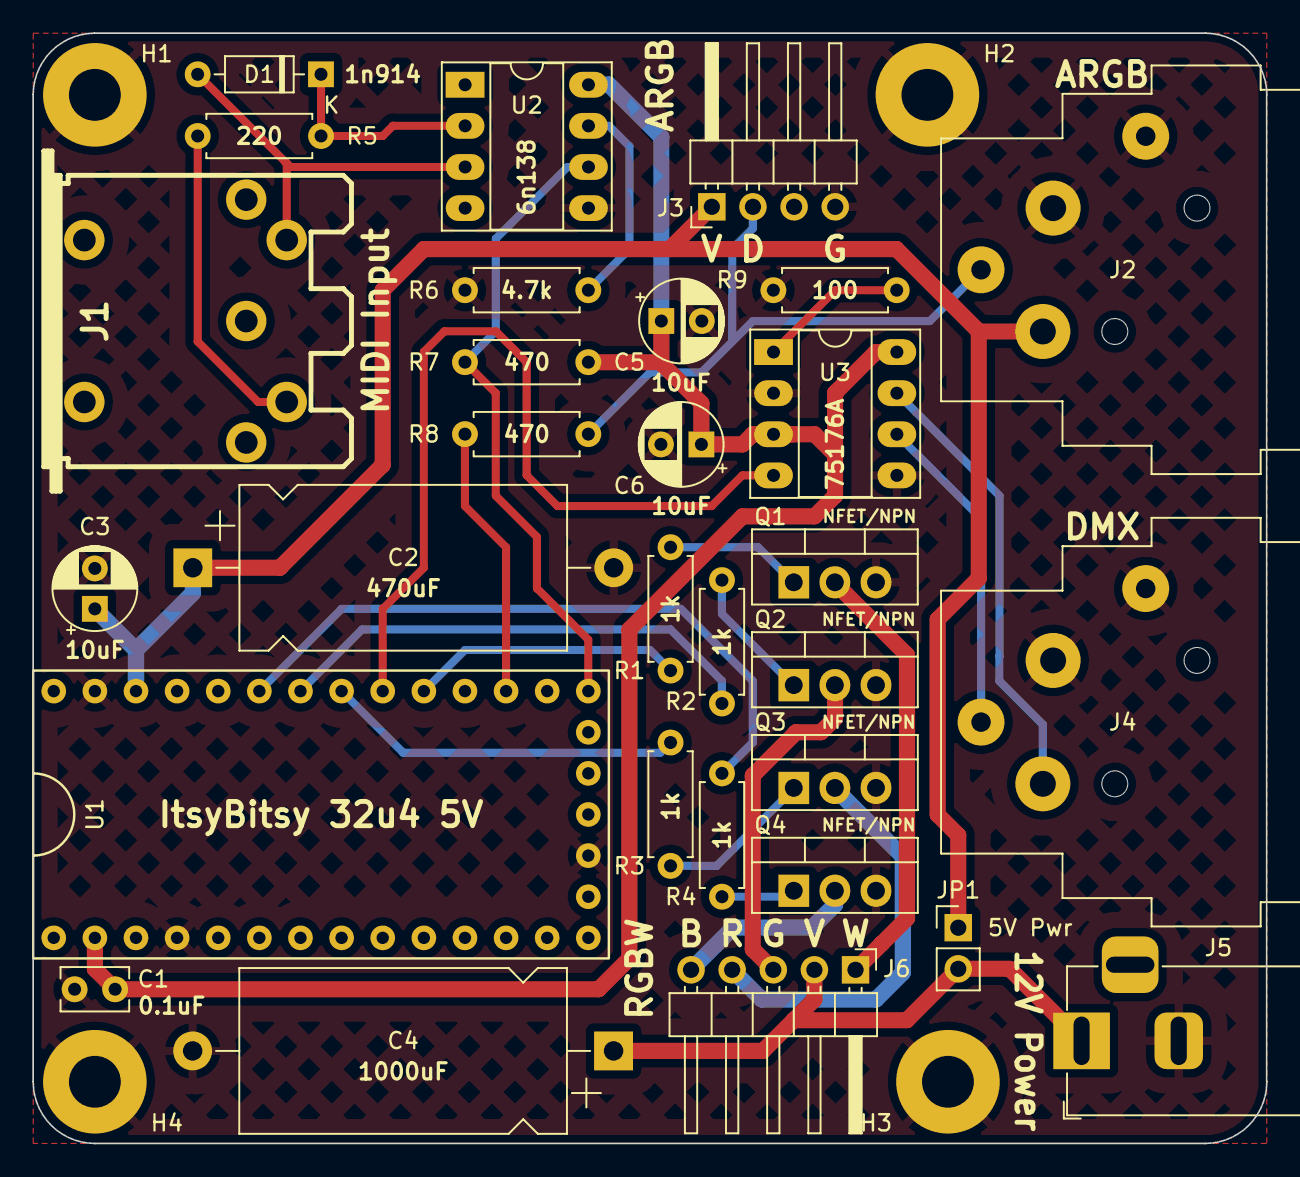
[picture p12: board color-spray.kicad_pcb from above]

Board: 2 copper layers, 76.2 x 68.6 mm, 34 parts (0 on the bottom side), 27 nets.

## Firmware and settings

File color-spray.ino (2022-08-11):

/**
 * Title:       Color Spray
 * Created by:  Cooper Dalrymple
 * Date:        2022-05-06
 * License:     GNU GPL v3.0
 * Version:     1.0
 */

#define ARGB_ENABLED    true
#define DMX_ENABLED     true
#define RGBW_ENABLED    true

#define USB_MIDI        true
#define USB_TIMEOUT     2000 // Only used for serial debugging

#if USB_MIDI
#include <USB-MIDI.h>
#else
#include <MIDI.h>
#endif
USING_NAMESPACE_MIDI;

struct CustomMidiSettings : public MIDI_NAMESPACE::DefaultSettings {
    static const unsigned SysExMaxSize = 32;
};
typedef Message<CustomMidiSettings::SysExMaxSize> MidiMessage;
typedef MIDI_NAMESPACE::MidiType MidiType;

#if USB_MIDI
#define UsbMidiMessage MIDI_NAMESPACE::MidiInterface<USBMIDI_NAMESPACE::usbMidiTransport, CustomMidiSettings>::MidiMessage
USBMIDI_CREATE_CUSTOM_INSTANCE(0, MIDICoreUSB, CustomMidiSettings);
#endif

#define SerialMidiMessage MIDI_NAMESPACE::MidiInterface<MIDI_NAMESPACE::SerialMIDI<HardwareSerial>, CustomMidiSettings>::MidiMessage
MIDI_CREATE_CUSTOM_INSTANCE(HardwareSerial, Serial1, MIDICoreSerial, CustomMidiSettings);

#if ARGB_ENABLED
#include "controller_argb.h"
#endif
#if DMX_ENABLED
#include "controller_dmx.h"
#endif
#if RGBW_ENABLED
#include "controller_rgbw.h"
#endif

#include "sysex.h"
#include "color.h"
#include "palettes.h"
#include "preset.h"
#include "settings.h"

#define LED             13
#define LED_DURATION    10

#define ARGB_MAX        120
#if ARGB_ENABLED
#define ARGB_PIN        2
#define ARGB_ORDER      GRB
#define ARGB_TYPE       WS2812B
static ARGB_TYPE<ARGB_PIN, ARGB_ORDER> argbController;
uint8_t modArgb = 1;
#endif

#define DMX_MAX         32
#if DMX_ENABLED
#define DMX_PIN         7
#define DMX_ORDER       RGB
static DmxController<DMX_PIN, DMX_ORDER> dmxController;
uint8_t modDmx = 1;
#endif

#if RGBW_ENABLED
#define RGBW_R           9
#define RGBW_G           10
#define RGBW_B           11
#define RGBW_W           5
static RgbwController<RGBW_R, RGBW_G, RGBW_B, RGBW_W> rgbwController;
#endif

#define COLOR_UPDATE    10 // ms
#define PALETTE_UPDATE  2 // ms
#define PALETTE_CHANGES 48
#define PALETTE_ITERS   1
#define PALETTE_MAX     16
#define PALETTE_BLEND   LINEARBLEND
PresetData current_preset = default_preset;
CRGBPalette16 current_palette(CRGB::Black);

Settings settings;

void configure();
void loadPreset(uint8_t i);

#if USB_MIDI
void messageUartToUsb(MidiMessage message);
void messageUsbToUart(MidiMessage message);
#endif
void controlChange(byte channel, byte control, byte value);
void programChange(byte channel, byte program);

void setup() {
    pinMode(LED, OUTPUT);
    digitalWrite(LED, HIGH);

    pinMode(0, INPUT);
    pinMode(1, OUTPUT);

    #if USB_MIDI
    #else
    Serial.begin(9600);
    #endif

    #if USB_MIDI
    MIDICoreSerial.setHandleMessage(messageUartToUsb);
    #endif
    MIDICoreSerial.setHandleControlChange(controlChange);
    MIDICoreSerial.setHandleProgramChange(programChange);
    MIDICoreSerial.setHandleNoteOn(noteOn);
    MIDICoreSerial.setHandleSystemExclusive(systemExclusive);

    #if USB_MIDI
    MIDICoreUSB.turnThruOff();
    MIDICoreUSB.setHandleMessage(messageUsbToUart);
    MIDICoreUSB.setHandleControlChange(controlChange);
    MIDICoreUSB.setHandleProgramChange(programChange);
    MIDICoreUSB.setHandleNoteOn(noteOn);
    MIDICoreUSB.setHandleSystemExclusive(systemExclusive);
    #endif

    MIDICoreSerial.begin(MIDI_CHANNEL_OMNI);
    #if USB_MIDI
    MIDICoreUSB.begin(MIDI_CHANNEL_OMNI);
    #endif

    configure();

    digitalWrite(LED, LOW); // Indicate that initialization is complete
}

void configure() {
    #if USB_MIDI
    #else
    unsigned long usb_start = millis();
    while (!Serial && millis() - usb_start < USB_TIMEOUT) { }
    if (Serial) {
        Serial.println(F("Color Spray - Version 1.0 - 2022 Cooper Dalrymple"));

        Serial.print(F("Midi Thru: "));
        if (settings.data.midiThru) {
            Serial.print(F("On"));
        } else {
            Serial.print(F("Off"));
        }
        Serial.println();

        Serial.print(F("Midi Channel: "));
        if (settings.data.midiChannel > 0) {
            Serial.print(settings.data.midiChannel);
        } else {
            Serial.print(F("Omni"));
        }
        Serial.println();
    }
    #endif

    // MIDI
    if (settings.data.midiThru) {
        MIDICoreSerial.turnThruOn();
    } else {
        MIDICoreSerial.turnThruOff();
    }

    // ARGB
    #if ARGB_ENABLED
    argbController.setCount(min(settings.data.argbCount, ARGB_MAX));
    if (settings.data.argbCount > 0) {
        modArgb = max(floor((float)min(settings.data.dmxCount, DMX_MAX) / (float)min(settings.data.argbCount, ARGB_MAX)), 1);
    }
    #endif

    // DMX
    #if DMX_ENABLED
    dmxController.configure(&settings.data);
    dmxController.setCount(min(settings.data.dmxCount, DMX_MAX));
    if (settings.data.dmxCount > 0) {
        modDmx = max(floor((float)min(settings.data.argbCount, ARGB_MAX) / (float)min(settings.data.dmxCount, DMX_MAX)), 1);
    }
    #endif

    // Load Default Preset
    if (settings.data.preset > 0) {
        loadPreset(settings.data.preset - 1);
    }
}

CRGBPalette16 target_palette(CRGB::Black);
uint8_t palette_index = 0;
float palette_pos = 0;

unsigned long color_millis = -1;
unsigned long palette_millis = -1;
unsigned long led_millis = -1;

#if USB_MIDI
void messageUartToUsb(MidiMessage message) {
    MIDICoreUSB.send(message);
}
void messageUsbToUart(MidiMessage message) {
    MIDICoreSerial.send(message);
}
#endif

unsigned long curr_millis;
void loop() {
    curr_millis = millis();

    if (color_millis >= 0 && curr_millis - color_millis > COLOR_UPDATE) {
        color_millis = curr_millis;

        palette_pos += current_preset.palette_speed / 32.0f;
        if (palette_pos >= 256.0f) palette_pos -= 256.0f;
        palette_index = (uint8_t)palette_pos;

        #if ARGB_ENABLED
        argbController.show();
        #endif
        #if DMX_ENABLED
        dmxController.show();
        #endif
        #if RGBW_ENABLED
        rgbwController.show();
        #endif
    }

    if (palette_millis >= 0 && curr_millis - palette_millis > COLOR_UPDATE) {
        palette_millis = curr_millis;

        #if PALETTE_ITERS > 1
        for (uint8_t i = 0; i < PALETTE_ITERS; i++) {
            nblendPaletteTowardPalette(current_palette, target_palette, PALETTE_CHANGES);
        }
        #else
        nblendPaletteTowardPalette(current_palette, target_palette, PALETTE_CHANGES);
        #endif
    }

    if (led_millis >= 0 && curr_millis - led_millis > LED_DURATION) {
        digitalWrite(LED, LOW);
        led_millis = -1;
    }

    MIDICoreSerial.read();
    #if USB_MIDI
    MIDICoreUSB.read();
    #endif
}

void triggerLed() {
    digitalWrite(LED, HIGH);
    led_millis = millis();
}

// LED Functions

void mode_colorOff(CRGB *c, uint8_t index, uint16_t count) {
    *c = CRGB::Black;
}
void mode_solidRgb(CRGB *c, uint8_t index, uint16_t count) {
    *c = current_preset.color_rgb;
}
void mode_solidHsv(CRGB *c, uint8_t index, uint16_t count) {
    *c = current_preset.color_hsv;
}

void mode_palette(CRGB *c, uint8_t index, uint16_t count) {
    if (index > count) return;
    *c = ColorFromPalette(current_palette, palette_index + index, 255, PALETTE_BLEND); // 255 = brightness
}
#if ARGB_ENABLED
void mode_palette_argb(CRGB *c, uint8_t index, uint16_t count) {
    mode_palette(c, index * modArgb, count);
}
#endif
#if DMX_ENABLED
void mode_palette_dmx(CRGB *c, uint8_t index, uint16_t count) {
    mode_palette(c, index * modDmx, count);
}
#endif

void updatePalette() {
    RgbCallback cb;
    switch (current_preset.mode) {
        case ColorOff:
            cb = &mode_colorOff;
        case SolidRgb:
            cb = &mode_solidRgb;
            break;
        case SolidHsv:
            cb = &mode_solidHsv;
            break;
        case Palette:
            cb = &mode_palette;
            target_palette = *GlobalPalettes[current_preset.palette];
            break;
        case ChaseRgb:
        case ChaseHsv:
            cb = &mode_palette;

            CRGB *entries = new CRGB[PALETTE_MAX];
            for (uint8_t i = 0; i < PALETTE_MAX; i++) {
                entries[i] = CRGB::Black;
            }
            uint8_t count = constrain(current_preset.chase_count, 1, 8);
            uint8_t step = PALETTE_MAX / count;
            for (uint8_t i = 0; i < PALETTE_MAX; i += step) {
                if (current_preset.mode == ChaseRgb) {
                    entries[i] = current_preset.color_rgb;
                } else {
                    entries[i] = current_preset.color_hsv;
                }
            }
            target_palette = CRGBPalette16(entries);
            delete entries;
            break;
    }

    if (cb == &mode_palette) {
        #if ARGB_ENABLED
        argbController.setCallback(&mode_palette_argb);
        #endif
        #if DMX_ENABLED
        dmxController.setCallback(&mode_palette_dmx);
        #endif
    } else {
        #if ARGB_ENABLED
        argbController.setCallback(cb);
        #endif
        #if DMX_ENABLED
        dmxController.setCallback(cb);
        #endif
    }
    #if RGBW_ENABLED
    rgbwController.setCallback(cb);
    #endif
}

void loadPreset(uint8_t i) {
    settings.presetcpy(&current_preset, i);
    updatePalette();
}

// Midi Events

bool updated = false;
void controlChange(byte channel, byte control, byte value) {
    if (settings.data.midiChannel > 0 && channel != settings.data.midiChannel - 1) return;

    updated = false;
    switch (control) {

        // Palette Controls (Effect Controller 1-2)
        case 12:
            current_preset.palette = map(value, 0, 127, 0, PALETTE_COUNT);
            if (current_preset.palette >= PALETTE_COUNT) current_preset.palette = PALETTE_COUNT - 1;
            updated = true;
            break;
        case 13:
            current_preset.palette_speed = value;
            updated = true;
            break;

        // RGB Controls (General Purpose Controller 1-4)
        case 16:
            current_preset.color_rgb.r = value*2;
            updated = true;
            break;
        case 17:
            current_preset.color_rgb.g = value*2;
            updated = true;
            break;
        case 18:
            current_preset.color_rgb.b = value*2;
            updated = true;
            break;

        // HSV Controls (General Purpose Controller 5-8)
        case 80:
            current_preset.color_hsv.h = value*2;
            updated = true;
            break;
        case 81:
            current_preset.color_hsv.s = value*2;
            updated = true;
            break;
        case 82:
            current_preset.color_hsv.v = value*2;
            updated = true;
            break;

        // Chase Controls
        case 83:
            current_preset.chase_count = map(value, 0, 127, 0, 7);
            if (current_preset.chase_count > 7) current_preset.chase_count = 7;
            current_preset.chase_count++;
            updated = true;
            break;

    }

    if (updated) {
        triggerLed();
        updatePalette();
    }
}

void programChange(byte channel, byte program) {
    if (settings.data.midiChannel > 0 && channel != settings.data.midiChannel - 1) return;

    if (program == 0) {
        current_preset.mode = ColorOff;
    } else if (program < 1 + PRESET_COUNT) {
        loadPreset(program - 1);
    } else if (program < 1 + PRESET_COUNT + COLOR_MODES - 1) {
        current_preset.mode = (ColorMode)(program - 1 - PRESET_COUNT + 1);
    }

    if (program < PRESET_COUNT + COLOR_MODES) {
        triggerLed();
        updatePalette();
    }
}

void noteOn(byte channel, byte note, byte velocity) {
    if (settings.data.midiChannel > 0 && channel != settings.data.midiChannel - 1) return;
    if (velocity == 0) return;

    for (uint8_t i = 0; i < PRESET_COUNT; i++) {
        if (settings.presets[i].note == note) {
            loadPreset(i);
            triggerLed();
            break;
        }
    }
}

void systemExclusive(byte* data, unsigned size) {
    bool valid = size >= 5 && data[1] == MANUFACTURER_ID && data[2] == DEVICE_ID;

    #if USB_MIDI
    #else
    if (Serial) {

        Serial.print(F("Sysex Message Received ("));
        Serial.print(size);
        Serial.println(F(" bytes in total):"));
        if (valid) {
            Serial.print(F("Message is Valid"));
        } else {
            Serial.print(F("Invalid Message"));
        }
        Serial.println();
        Serial.println(F("Message Contents:"));
        for (uint8_t i = 0; i < size; i++) {
            Serial.print("0x");
            Serial.print(data[i], HEX);
            Serial.print(" ");
            if ((i > 0 && i % 8 == 0) || i == size - 1) {
                Serial.println();
            }
        }
        Serial.println();
    }
    #endif

    if (!valid) return;
    triggerLed();

    unsigned response_size = 3;
    switch (data[0x03]) {
        case COMMAND_READ_VERSION:
            response_size = 4;
            break;
        case COMMAND_READ_SETTINGS:
            response_size = 4 + sizeof(SettingsData);
            break;
        case COMMAND_READ_PRESET:
            if (size >= 5 && data[0x04] < PRESET_COUNT) {
                response_size = 4 + sizeof(PresetData);
            }
            break;
    }
    byte* response = new byte[response_size];
    response[0x00] = MANUFACTURER_ID;
    response[0x01] = DEVICE_ID;
    response[0x02] = RESPONSE_ERROR;

    switch (data[0x03]) {
        case COMMAND_ALIVE:
            response[0x02] = RESPONSE_SUCCESS;
            break;
        case COMMAND_RESET:
            configure();
            response[0x02] = RESPONSE_SUCCESS;
            break;

        case COMMAND_READ_VERSION:
            response[0x02] = RESPONSE_SUCCESS;
            response[0x03] = SETTINGS_VERSION;
            break;
        case COMMAND_READ_SETTINGS:
            response[0x02] = RESPONSE_SUCCESS;
            response[0x03] = SETTINGS_VERSION;
            settings.datacpy(response+4, true);
            break;
        case COMMAND_READ_PRESET:
            if (size >= 5 && data[0x04] < PRESET_COUNT) {
                response[0x02] = RESPONSE_SUCCESS;
                response[0x03] = SETTINGS_VERSION;
                settings.presetcpy(response+4, data[0x04], true);
            }
            break;

        case COMMAND_WRITE_SETTINGS:
            if (size == 5 + sizeof(SettingsData) + 1 && data[0x04] == SETTINGS_VERSION) {
                settings.datawrite(data+5, true);
                response[0x02] = RESPONSE_SUCCESS;
            }
            break;
        case COMMAND_WRITE_PRESET:
            if (size == 6 + sizeof(PresetData) + 1 && data[0x04] == SETTINGS_VERSION && data[0x05] < PRESET_COUNT) {
                settings.presetwrite(data+6, data[0x05], true);
                response[0x02] = RESPONSE_SUCCESS;
            }
            break;
    }

    MIDICoreSerial.sendSysEx(response_size, response);
    #if USB_MIDI
    MIDICoreUSB.sendSysEx(response_size, response);
    #endif
    delete response;
}

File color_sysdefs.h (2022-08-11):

#ifndef LED_SYSDEFS_H
#define LED_SYSDEFS_H

#include <Arduino.h>

#define FASTLED_SCALE8_FIXED 1
#define FASTLED_BLEND_FIXED 1
#define FASTLED_NOISE_FIXED 1
#ifndef FASTLED_INTERRUPT_RETRY_COUNT
#define FASTLED_INTERRUPT_RETRY_COUNT 2
#endif

#define FASTLED_AVR

#ifndef INTERRUPT_THRESHOLD
#define INTERRUPT_THRESHOLD 2
#endif

#define FASTLED_SPI_BYTE_ONLY

#include <avr/io.h>
#include <avr/interrupt.h> // for cli/se definitions

// Define the register types
typedef volatile       uint8_t RoReg; /**< Read only 8-bit register (volatile const unsigned int) */
typedef volatile       uint8_t RwReg; /**< Read-Write 8-bit register (volatile unsigned int) */


// Default to disallowing interrupts (may want to gate this on teensy2 vs. other arm platforms, since the
// teensy2 has a good, fast millis interrupt implementation)
#ifndef FASTLED_ALLOW_INTERRUPTS
#define FASTLED_ALLOW_INTERRUPTS 0
#endif

#if FASTLED_ALLOW_INTERRUPTS == 1
#define FASTLED_ACCURATE_CLOCK
#endif


// Default to using PROGMEM here
#ifndef FASTLED_USE_PROGMEM
#define FASTLED_USE_PROGMEM 1
#endif

#if defined(ARDUINO_AVR_DIGISPARK) || defined(ARDUINO_AVR_DIGISPARKPRO)
#ifndef NO_CORRECTION
#define NO_CORRECTION 1
#endif
#endif

extern "C" {
#  if defined(CORE_TEENSY) || defined(TEENSYDUINO)
extern volatile unsigned long timer0_millis_count;
#    define MS_COUNTER timer0_millis_count
#  elif defined(ATTINY_CORE)
extern volatile unsigned long millis_timer_millis;
#    define MS_COUNTER millis_timer_millis
#  elif defined(__AVR_ATmega4809__)
extern volatile unsigned long timer_millis;
#    define MS_COUNTER timer_millis
#  else
extern volatile unsigned long timer0_millis;
#    define MS_COUNTER timer0_millis
#  endif
};

// special defs for the tiny environments
#if defined(__AVR_ATmega32U2__) || defined(__AVR_ATmega16U2__) || defined(__AVR_ATmega8U2__) || defined(__AVR_AT90USB162__) || defined(__AVR_ATtiny24__) || defined(__AVR_ATtiny44__) || defined(__AVR_ATtiny84__) || defined(__AVR_ATtiny25__) || defined(__AVR_ATtiny45__) || defined(__AVR_ATtiny85__) || defined(__AVR_ATtiny167__) || defined(__AVR_ATtiny87__) || defined(__AVR_ATtiny88__) || defined(__AVR_ATtinyX41__) || defined(__AVR_ATtiny841__) || defined(__AVR_ATtiny441__)
#define LIB8_ATTINY 1
#define FASTLED_NEEDS_YIELD
#endif

#if defined(ARDUINO) && (ARDUINO > 150) && !defined(IS_BEAN) && !defined (ARDUINO_AVR_DIGISPARK) && !defined (LIB8_TINY) && !defined (ARDUINO_AVR_LARDU_328E)
// don't need YIELD defined by the library
#else
#define FASTLED_NEEDS_YIELD
extern "C" void yield();
#endif
#endif

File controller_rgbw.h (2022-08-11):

#ifndef RGBW_H
#define RGBW_H

#include "controller.h"

template<uint8_t R_PIN, uint8_t G_PIN, uint8_t B_PIN, uint8_t W_PIN>
class RgbwController : public Controller {

public:
    RgbwController() {
        pinMode(R_PIN, OUTPUT);
        analogWrite(R_PIN, 0);
        pinMode(G_PIN, OUTPUT);
        analogWrite(G_PIN, 0);
        pinMode(B_PIN, OUTPUT);
        analogWrite(B_PIN, 0);
        pinMode(W_PIN, OUTPUT);
        analogWrite(W_PIN, 0);
    };
    void show() {
        if (!this->valid()) return;
        this->_callback(&_c, 0, 1);
        this->sendPixel(0);
    };
    bool valid() {
        return this->_callback != NULL;
    };

private:
    inline void sendPixel(uint16_t index) {
        if (index > 0) return;
        analogWrite(R_PIN, this->_c.r);
        analogWrite(G_PIN, this->_c.g);
        analogWrite(B_PIN, this->_c.b);
        analogWrite(W_PIN, this->getW());
    };
    uint8_t getW() {
        return min(this->_c.r, min(this->_c.g, this->_c.b));
    };

};

#endif

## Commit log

2022-05-07 First prototype build of hardware & software.
    [arduino-midi-argb-dmx.kicad_pcb, arduino-midi-argb-dmx.kicad_sch]
2022-05-07 Revision 1 of PCB. Provided support for 5V or 12V analog LED strips.
    [arduino-midi-argb-dmx-B_Courtyard.gbr, arduino-midi-argb-dmx-B_Cu.gbr, arduino-midi-argb-dmx-B_Fab.gbr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]
2022-05-25 Led Trigger, Usb Midi/Debug option, Hardware Thru, Palette Changes refinement, Color Off mode, Program Change mode, CC codes, and more.
2022-05-25 Hardware BOM
    [arduino-midi-argb-dmx.csv, arduino-midi-argb-dmx_bom.ods]
2022-05-27 FreeCAD Enclosure
    [arduino-midi-argb-dmx-enclosure-bottom.stl, arduino-midi-argb-dmx-enclosure-dc-cap.stl, arduino-midi-argb-dmx-enclosure.FCStd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]
2022-05-27 DMX TX pin fix.
2022-05-31 Switched from MIDIUSB to Arduino USB-MIDI Transport to consolidate midi logic.
2022-06-02 Reorganization and renaming.
    [color-spray-B_Courtyard.gbr, color-spray-B_Cu.gbr, color-spray-B_Fab.gbr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]
2022-06-03 Updated enclosure labels.
    [arduino-midi-argb-dmx-enclosure-bottom.stl, arduino-midi-argb-dmx-enclosure-dc-cap.stl, arduino-midi-argb-dmx-enclosure.FCStd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]
2022-06-04 DMX RGB order fix.
    [color-spray.ino]
2022-06-04 Dynamic configuration with new sysex reset command.
    [color-spray.ino]
2022-06-04 Added OSHWA certification mark to PCB and README.
    [color-spray.kicad_pcb]
